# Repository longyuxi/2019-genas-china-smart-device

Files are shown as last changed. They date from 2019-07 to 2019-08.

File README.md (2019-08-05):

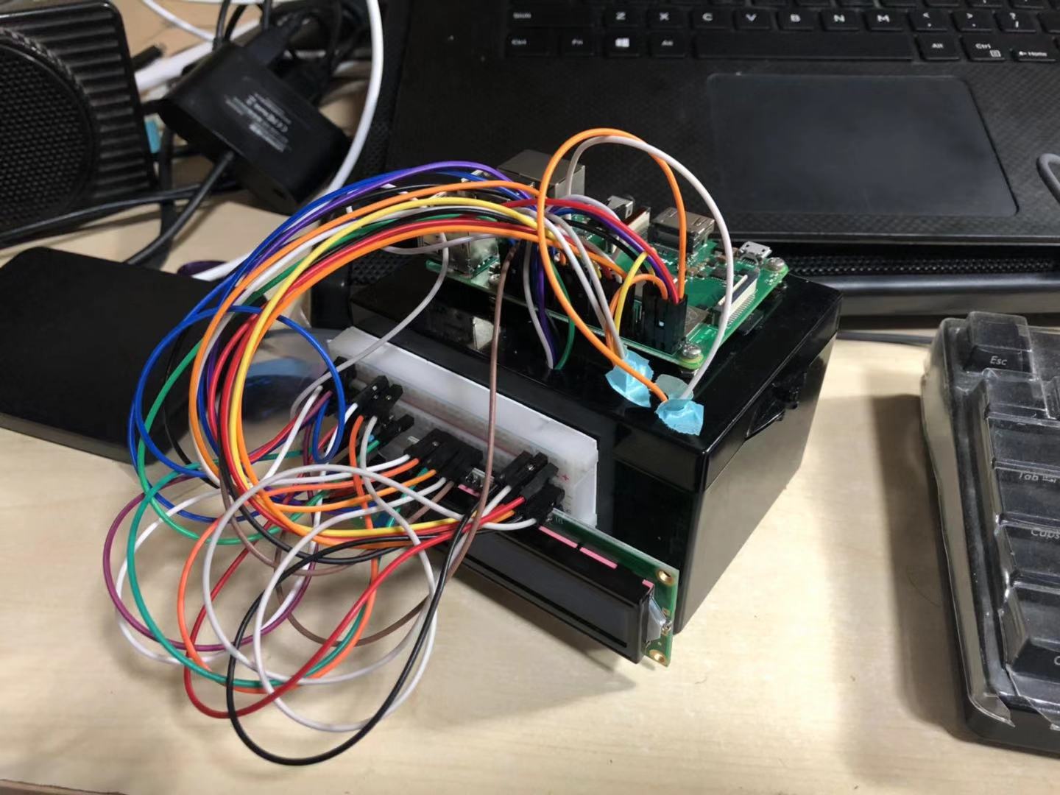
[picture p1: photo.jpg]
Photo of device

# Features
## Introduction
Welcome to the hardware for 2019 iGEM team GENAS_China. Our team aims at creating a modular way to detect the concentration of certain small molecules in the human body as disease indicators. The hardware appliance is to be used in couple with our detection liquid based on a genetically modified strand of the *E. Coli* O157. For a detailed description on our project, check us out on the [iGEM website](https://2019.igem.org/Team:GENAS_China/Description) (still under construction) or the [CCiC compliant preview website](https://genas-china.onrender.com/).

Although our aim is that the user can directly see the danger level of the molecule (as indicated by the liquid turning into different colors), the hardware is meant to quanitfy the concentration level as well as complementing the previous method when determing the danger of a certain molecule requires more precision than the previous method can offer. 

The intuition behind the hardware is that the blue lights emitted from the bottom of the box pass through the sample liquid on a piece of translucent paper and excite the flourescent protein in the sample. The light is then received by a light intensity sensor, on which there is an ochre-colored filter, so that the level of excited flourescent light can be measured. The light is also received by an unfiltered color sensor, so that the color of the light can be measured. The measurements are then correlated with a pre-built math model to determine the concentration and mix formula of expressed flourescent protein, which is then used to find out the concentration level of the certain particle.

The current protoype is based on a Raspberry 3 Pi B+, but can be produced on a Pi Zero too, which cuts the cost of manufacturing to less than $30.

Startup script checks if all interfaces can be instantiated and print out the currently connected Wi-Fi network and its IP address for easy SSH for the developer. Should the user decide that he/she wants to enter the user mode, which outputs the measured concnetraion based on sample, he/she needs to push the button after the first LCD message.

## List of sensors currently installed:
- TCS34725 color (RGB) sensor with inaccurate light intensity function
- DS18B20 temperature sensor
- TSL2561 light intensity sensor

# Design diagrams
[1](https://33b68295032b152c.share.mingdao.net/apps/kcshare/5d46bb28eb60f43138261e44)
[2](https://33b68295032b152c.share.mingdao.net/apps/kcshare/5d46bb28eb60f43138261e44)
[3](https://33b68295032b152c.share.mingdao.net/apps/kcshare/5d46bb2aeb60f43bcc77df6b)

# User mode (model still under development)
## To enter user mode
Push the button when the LCD displays the Wi-Fi information. From there you can use the appliance to get concentration data from samples based on previous models (which are to be built).

## To use user mode
Put in your sample when the screen prompts you to. After you put in the sample, push the button and the machine will start analyzing it. When it is done analyzing, the measured concentration level will be printed out on the LCD screen and one of the LEDs (green, yellow, red) will light up to indicate the status of your sample (good, worse, bad). Then when you are done viewing the results of this sample, push the button again and start over from the beginning of this paragraph.

# Startup sequence
To run the startup script, type `sudo python practice.py` in the terminal when in this directory.
The startup script should detect most of the connection problems. Should there be no connection problems, events that would happen when you plug in are as follows:
- LCD screen prints out "LCD Success".
- LEDs show a light chasing sequence, then all flash three times.
- LCD screen prints out "All OK" on first line, "Lux=...,T=..." on second line.
- As soon as the Pi is connected to the network, LCD screen prints Wi-Fi network name on first line, local IP address on second line (which is the IP address you use to connect to the Pi).

Allow 30 seconds before the Pi starts the startup sequence above. Should the startup not abide to the sequence above, the LCD should print out the error (if the LCD is working in the first place). Refer to the "Errors" section below for more information.

# Setting up the hardware and software
 
1. Use Etcher to flash Raspbian image to the Pi.

2. Add an empty file named `ssh` to the **boot partition**.  This enables the ssh daemon when it boots.

3. Edit these files on the **OS partition**:
  * Edit `/etc/hostname` and `/etc/hosts` to change “raspberrypi” to a **unique host name**, like `smart-detector-pi`.
  * Edit `/etc/wpa_supplicant/wpa_supplicant.conf` to add your WiFi authentication (updating "country" if appropriate):

```
country=us
update_config=1
ctrl_interface=/var/run/wpa_supplicant

network={
 scan_ssid=1
 ssid="your WiFi name (SSID)"
 psk="your WiFi password"
}
```

4. Use an IP scanner (such as the "Advanced IP Scanner" for Windows) to scan the network of the Pi. Once you find a device with the special name that you set in step 3, copy down its IP Address. Then use PuTTY to connect to the Pi via SSH by changing the `hostname or IP address` field to the one that you found.

5. Run the following commands to start the setup script.
```
wget https://raw.githubusercontent.com/longyuxi/2019-genas-china-smart-device/master/setup.sh
chmod +x ./setup.sh
sudo ./setup.sh
```

6. Run `crontab -e` and append the line `@reboot sudo python /home/pi/2019-genas-china-smart-device/practice.py &` to run the script at startup. 

# To view the wiring diagram

Download *Fritzing* to open the .fzz file. You possibly need to download the Fritzing parts file for TCS34725.

# To log data

Currently, in order to log the data, you have to SSH into the Pi and run a Python script. This will be improved in the future.

1. When in the `2019-genas-china-smart-device` directory, run `sudo python record_data.py`. Make sure the box is empty.
2. Leave the lid closed until the script prompts you to insert your sample.
3. Open the lid.
4. Put in/replace the sample.
5. Key in the flow cytometry-determined flourescent value and press ENTER.
6. Repeat from step 3. When you are done, hit *CTRL + C* on your keyboard to exit the program.

The file is automatically saved every time you press ENTER, so no worries if the power goes out.

# Potential errors and error messages
1. **There is no output on LCD**: There is probably a connection problem between the Pi and the LCD. Refer to the wiring diagram to correct the connection. If there is no problem in connection, there might be a problem auto-executing the script. Make sure you have followed all the steps in the setup section above.
2. **TCS34725 FAIL, LED FAIL, DS18B20 FAIL, TSL2561 FAIL or Emitter FAIL**: Refer to the wiring diagram to correct the wiring.
3. **Wi-Fi not connected**: Make sure you are in range of the Wi-Fi adapter. The wireless adapter on the Raspberry Pi might be less powerful than your computer or phone's Wi-Fi adapter.

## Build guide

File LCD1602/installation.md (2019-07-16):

https://www.mbtechworks.com/projects/drive-an-lcd-16x2-display-with-raspberry-pi.html

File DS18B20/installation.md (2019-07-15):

http://www.circuitbasics.com/raspberry-pi-ds18b20-temperature-sensor-tutorial/

Enable 1-wire

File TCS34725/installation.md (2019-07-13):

sudo pip install adafruit-tcs34725

Pi 3V3 to sensor VIN
Pi GND to sensor GND
Pi SCL to sensor SCL
Pi SDA to sensor SDA

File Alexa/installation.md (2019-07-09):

See https://developer.amazon.com/docs/alexa-voice-service/input-avs-credentials.html

```
wget https://raw.githubusercontent.com/alexa/avs-device-sdk/master/tools/Install/setup.sh
wget https://raw.githubusercontent.com/alexa/avs-device-sdk/master/tools/Install/genConfig.sh
wget https://raw.githubusercontent.com/alexa/avs-device-sdk/master/tools/Install/pi.sh

```

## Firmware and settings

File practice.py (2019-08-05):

import sys, os, imp, time
import RPi.GPIO as GPIO
import threading

GPIO.setmode(GPIO.BCM)

# # TODO a function that returns the detected particle concentration
# based on measurement data and mathematic model, possibly requires import of .mdl
# Currently a dummy function. 
def get_detected_level():
   led.emitter(True)
   time.sleep(1)
   res = TSL2561.fullSpectrumValue()
   return res

# TODO a function that reports detected level visually, viz. via LCD, LED
def report_result():
   result = get_detected_level()
   lcd.lcd_clear_screen()
   lcd.lcd_text('Lux = ', lcd.LCD_LINE_1)
   lcd.lcd_text(str(result), lcd.LCD_LINE_2)

# Pin to which the button to enter user mode is connected
PUSH_BUTTON_PIN = 21
GPIO.setup(PUSH_BUTTON_PIN, GPIO.IN, pull_up_down=GPIO.PUD_DOWN)
usermode = False
def enter_user_mode(channel):
   global usermode
   usermode = True
GPIO.add_event_detect(PUSH_BUTTON_PIN, GPIO.RISING, callback=enter_user_mode, bouncetime=200)


# The threshold used to confirm that blue light emitters are connected. 
# Set to be half of expected value when on.
EMITTER_THRESHOLD_LUX = 1000 

# Import LCD
# home_dir = os.path.expanduser("/home/pi/2019-genas-china-smart-device")
# lcd_file = os.path.join(home_dir, "LCD1602/lcd.py")
# lcd = imp.load_source('lcd', lcd_file)
try:
   import lcd
   lcd.setup()
   lcd_welcome = threading.Thread(target=lcd.lcd_success_message)
   lcd_welcome.start()
except:
   print("FATAL: LCD IMPORT FAILURE")
   exit()

# Import TCS34725
try:
   
   # tcs_file = os.path.join(home_dir, "TCS34725/Adafruit_TCS34725.py")
   # Adafruit_TCS34725 = imp.load_source('TCS34725', tcs_file)
   import Adafruit_TCS34725
   import smbus
   tcs = Adafruit_TCS34725.TCS34725()
   tcs.set_interrupt(True)
   r, g, b, c = tcs.get_raw_data()
   lux = Adafruit_TCS34725.calculate_lux(r, g, b)
   print('Current color in box: red={0} green={1} blue={2} clear={3}. Lux={4}'.format(r, g, b, c, lux))
   # TCS34725 functions
   # # Read the R, G, B, C color data.
   # r, g, b, c = tcs.get_raw_data()

   # # Calculate color temperature using utility functions.  You might also want to
   # # check out the colormath library for much more complete/accurate color functions.
   # color_temp = Adafruit_TCS34725.calculate_color_temperature(r, g, b)

   # # Calculate lux with another utility function.
   # lux = Adafruit_TCS34725.calculate_lux(r, g, b)
   # lcd.lcd_text('R={0} G={1} B={2} C={3} L={4}'.format(r, g, b, c, lux), lcd.LCD_LINE_2)
   # time.sleep(1)
   # lcd.lcd_clear_screen()
except:
   lcd.lcd_text("TCS34725 FAIL", lcd.LCD_LINE_2)
   exit()

# Import LED
try:
   import led
except:
   lcd.lcd_text("LED FAIL", lcd.LCD_LINE_2)
   exit()

# Import DS18B20
try:
   from w1thermsensor import W1ThermSensor
   temp_sensor = W1ThermSensor()
except:
   lcd.lcd_text("DS18B20 FAIL", lcd.LCD_LINE_2)
   exit()

# Import TSL2561
try:
   import TSL2561
except:
   lcd.lcd_text("TSL2561 FAIL", lcd.LCD_LINE_2)
   exit()

def testEmitter():
   led.emitter(True)
   blankValue = TSL2561.visibleValue()
   time.sleep(1)
   coloredValue = TSL2561.visibleValue()
   if (coloredValue - blankValue) < EMITTER_THRESHOLD_LUX:
      # Emitter not connected4
      lcd.lcd_text("Emitter FAIL", lcd.LCD_LINE_1)
      sys.exit()
   else:
      led.emitter(False)
      return
   

lcd_welcome.join()
emitterTest = threading.Thread(target=testEmitter)
emitterTest.start()
emitterTest.join()
led.emitter(False)
lcd.lcd_text("All OK", lcd.LCD_LINE_1)
lcd.lcd_text("Lux={0},T={1}".format(TSL2561.visibleValue(), temp_sensor.get_temperature()), lcd.LCD_LINE_2)
time.sleep(1)

# Print out Wi-Fi SSID and local IP address if connected
lcd.lcd_clear_screen()

# Tries to connect to Wi-Fi and print out 
# information only when not in usermode yet
if not usermode:
   count = 0
   while True:
      wifi_name = os.popen('iwgetid -r').read()
      wifi_name = wifi_name[0:(len(wifi_name)-1)].strip()
      if(wifi_name == ''):
         time.sleep(1)
         count = count + 1
      elif count > 15:
         break
      else:
         break

   if count > 15:
      lcd.lcd_text("Wi-Fi", lcd.LCD_LINE_1)
      lcd.lcd_text("Not connected", lcd.LCD_LINE_2)
   else:
      wifi_name = os.popen('iwgetid -r').read()
      wifi_name = wifi_name[0:(len(wifi_name)-1)].strip()
      ipaddr = os.popen('hostname -I').read()
      ipaddr = ipaddr[0:(len(ipaddr)-1)].strip()
      lcd.lcd_text(wifi_name, lcd.LCD_LINE_1)
      lcd.lcd_text(ipaddr, lcd.LCD_LINE_2)

tick = 0
while True:
   if usermode:
      break
   if tick > 15:
      sys.exit() # Exit program if user did not specify usermode in 15 seconds
   tick = tick + 1
   time.sleep(1)

# Usermode now
lcd.lcd_clear_screen()
lcd.lcd_text('User Mode', lcd.LCD_LINE_1)
GPIO.remove_event_detect(PUSH_BUTTON_PIN)
time.sleep(1)

while True:
   GPIO.output(led.WHITE_LED_PIN, True)
   lcd.lcd_clear_screen()
   lcd.lcd_text('Put in sample', lcd.LCD_LINE_1)
   lcd.lcd_text('Push btn on done', lcd.LCD_LINE_2)
   GPIO.wait_for_edge(PUSH_BUTTON_PIN, GPIO.RISING)
   GPIO.output(led.WHITE_LED_PIN, False)
   threading.Thread(target=led.blink_led, args=(led.BLUE_LED_PIN, 0.3, 0.3,)).start()
   lcd.lcd_clear_screen()
   lcd.lcd_text('Detecting', lcd.LCD_LINE_1)
   report_result()
   led.stop_blinking()
   GPIO.wait_for_edge(PUSH_BUTTON_PIN, GPIO.RISING)

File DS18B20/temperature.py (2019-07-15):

from email.mime.multipart import MIMEMultipart
from email.mime.text import MIMEText
import sys
import time
import logging
import threading
import RPi.GPIO as GPIO
import requests
import smtplib
import json
import tweepy
import os
from time import localtime, strftime
import paho.mqtt.publish as mqttpublish
from w1thermsensor import W1ThermSensor

from ConfigParser import SafeConfigParser
from tweepy import OAuthHandler as TweetHandler
from slackclient import SlackClient

PUSHOVER_SOUNDS = None

seconds_started = 10000
temp_sensor = W1ThermSensor()

def email(msg):
    try:
        message = MIMEMultipart('related')
        message['Subject'] = msg
        message['From'] = email_sender
        message['To'] = email_recipient
        message.preamble = 'This is a multi=part message in MIME format.'

        message_alternative = MIMEMultipart('alternative')
        message.attach(message_alternative)
        message_text = MIMEText(msg + '\n')

        message_text = MIMEText('<h3>' + msg + '</h3>')

        message_text.replace_header('Content-Type', 'text/html')
        message_alternative.attach(message_text)

        s = smtplib.SMTP(email_server, email_port)
        s.starttls()
        s.login(email_sender, email_password)
        s.sendmail(email_sender, email_recipient, message.as_string())
        s.quit()
    except (KeyboardInterrupt, SystemExit):
        raise
    except:
        pass


def mqtt(msg):
    try:
        mqtt_auth = None
        if len(mqtt_username) > 0:
            mqtt_auth = { 'username': mqtt_username, 'password': mqtt_password }

        mqttpublish.single(mqtt_topic, msg, qos=0, retain=False, hostname=mqtt_hostname,
        port=mqtt_port, client_id=mqtt_clientid, keepalive=60, will=None, auth=mqtt_auth,
        tls=None)
    except (KeyboardInterrupt, SystemExit):
        raise
    except:
        pass

def pushbullet(cfg, msg):
    try:
        data_send = {"type": "note", "body": msg}
        requests.post(
            'https://api.pushbullet.com/v2/pushes',
            data=json.dumps(data_send),
            headers={'Authorization': 'Bearer ' + cfg,
                     'Content-Type': 'application/json'})
    except (KeyboardInterrupt, SystemExit):
        raise
    except:
        pass

def get_pushoversounds(app_key):
    global PUSHOVER_SOUNDS

    if not PUSHOVER_SOUNDS:
        url_data = "https://api.pushover.net/1/sounds.json?token={}" .format(app_key)

        try:
            r = requests.get(url_data)
            json_data = r.json()
            PUSHOVER_SOUNDS = json_data['sounds']
        except (KeyboardInterrupt, SystemExit):
            raise
        except:
            pass


def pushover(user_key, app_key, msg, device='', sound=''):
    global PUSHOVER_SOUNDS

    if not PUSHOVER_SOUNDS:
        get_pushoversounds(app_key)

    data_send = {"user": user_key, "token": app_key, "message": msg}

    if device:
        data_send['device'] = device

    if sound in PUSHOVER_SOUNDS:
        data_send['sound'] = sound

    try:
        requests.post(
            'https://api.pushover.net/1/messages.json',
            data=json.dumps(data_send),
            headers={'Content-Type': 'application/json'})
    except (KeyboardInterrupt, SystemExit):
        raise
    except:
        pass

def iftt(msg):
    try:
        iftt_url = "https://maker.ifttt.com/trigger/{}/with/key/{}".format(iftt_maker_channel_event,
                                                                           iftt_maker_channel_key)
        report = {"value1" : msg}
        resp = requests.post(iftt_url, data=report)
    except (KeyboardInterrupt, SystemExit):
        raise
    except:
        pass

def slack_webhook(msg):
    try:
        requests.post(slack_webhook_url, json={'text': msg}, headers={"Content-type": "application/json"})
    except (KeyboardInterrupt, SystemExit):
        raise
    except:
        pass

def tweet(msg):
    try:
        # Twitter is the only API that NEEDS something like a timestamp,
        # since it will reject identical tweets.
        tweet = msg + ' ' + strftime("%Y-%m-%d %H:%M:%S", localtime())
        auth = TweetHandler(twitter_api_key, twitter_api_secret)
        auth.set_access_token(twitter_access_token,
                              twitter_access_token_secret)
        tweepy.API(auth).update_status(status=tweet)
    except (KeyboardInterrupt, SystemExit):
        raise
    except:
        pass


def slack(msg):
    try:
        slack = msg + ' ' + strftime("%Y-%m-%d %H:%M:%S", localtime())
        sc = SlackClient(slack_api_token)
        sc.api_call(
            'chat.postMessage', channel='#random', text=slack)
    except (KeyboardInterrupt, SystemExit):
        raise
    except:
        pass


def send_alert(message):
    if len(message) > 1:
        logging.info(message)
        if len(pushover_user_key) > 0 and len(pushover_app_key) > 0:
            pushover(pushover_user_key, pushover_app_key, message, pushover_device, pushover_sound)
        if len(pushbullet_api_key) > 0:
            pushbullet(pushbullet_api_key, message)
        if len(pushbullet_api_key2) > 0:
            pushbullet(pushbullet_api_key2, message)
        if len(twitter_api_key) > 0:
            tweet(message)
        if len(slack_api_token) > 0:
            slack(message)
        if len (slack_webhook_url) > 0:
            slack_webhook(message)
        if len(iftt_maker_channel_key) > 0:
            iftt(message)
        if len(mqtt_topic) > 0:
            mqtt(message)
        if len(email_recipient) > 0:
            email(message)

def send_appliance_active_message():
    send_alert(start_message)
    global appliance_active
    appliance_active = True


def send_appliance_inactive_message():
    send_alert(end_message)
    global appliance_active
    appliance_active = False


def vibrated(x):
    global vibrating
    global last_vibration_time
    global start_vibration_time
    logging.debug('Vibrated')
    last_vibration_time = time.time()
    if not vibrating:
        start_vibration_time = last_vibration_time
        vibrating = True

def send_temperature():
    current_time = strftime("%Y-%m-%d %H:%M:%S", localtime())
    message = "Temperature at {} is {} degrees".format(current_time, temp_sensor.get_temperature())
    send_alert(message)
    # global appliance_active
    # appliance_active = True
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

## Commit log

2019-07-15 added LED sample code and hardware diagram
    [GENAS Hardware Diagram.fzz]
2019-07-16 added LCD1602
    [GENAS Hardware Diagram straight.fzz, GENAS Hardware Diagram.fzz]
2019-07-17 added TSL2561 and a startup script
    [GENAS Hardware Diagram straight.fzz]
2019-07-21 added lag to record_data to compensate for I2C update rate
2019-07-21 updated sketch and turns off led in startup script
    [GENAS Hardware Diagram straight.fzz]
2019-08-04 added user mode
    [GENAS Hardware Diagram straight.fzz]
